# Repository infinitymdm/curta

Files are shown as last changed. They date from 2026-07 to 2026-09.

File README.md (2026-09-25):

# 3D-Printable Curta Type II

This repository contains my work on 3D-printable parts for a working Curta Type
II at 3:1 scale.

The 3D-printed curta so far

This work would not be possible without
[Marcus Wu's Curta Type I at 3x scale](https://www.thingiverse.com/thing:1943171),
[Mads Eskildsen's detailed Curta Type II model](https://www.thingiverse.com/thing:4146906),
and the treasure trove of engineering drawings on
[VCALC.net](https://www.vcalc.net/cu.htm). Marcus Wu's work informs many of the
manufacturing and assembly techniques used here for Mads Eskildsen's models. The
engineering drawings inform a few corrections to components from Eskildsen's
work.

# Components

Each subsection below contains a list of the component part numbers for the
relevant subsystem. I've tried to put these in roughly the same order that I
printed them in. Subsystem groupings are based on my own intuition about the way
the Curta Type II works.

Each subsection may also refer to a 3mf file containing the parts for that
subsystem. Not all parts match the original design. I've combined quite a few
into "composite" parts for convenience. Where this has been done, I've noted
where you can find my modified STL.

## Inner Frame

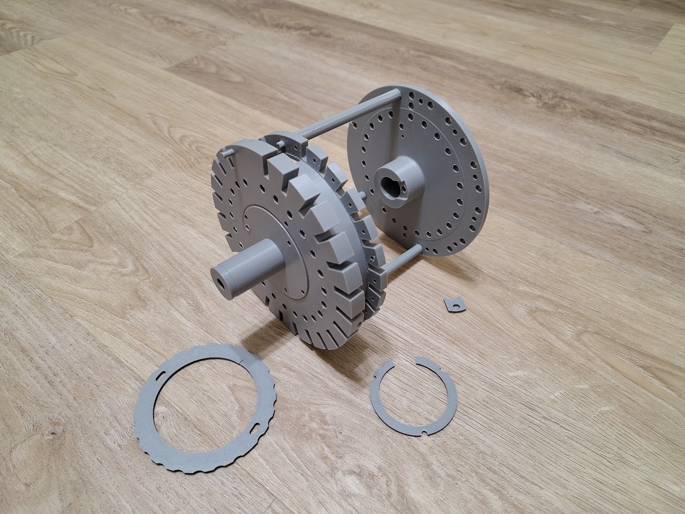
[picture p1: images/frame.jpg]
3D-printed Curta Type 2 frame components


See frame.3mf.

| Part Number | Quantity | Description |
| --- | --- | --- |
| 10154 | 1 | Name plate? |
| 2060 | 1 | Carriage body |
| 2030 | 1 | Bearing plate |
| 2062 | 3 | Frame columns |
| 2061 | 1 | Carriage stop pin |
| 2052 | 1 | Tens bell bearing plate |
| 2065 | 1 | Transmission crown hold-down plate |
| 10010 | 1 | Reversing ring guide |
| 10015 | 1 | Screw securing reversing ring guide to bearing plate |
| 10152 | 1 | Washer for 10015 (Not needed) |
| VSM 12124 3 | 7 | Tens bell bearing plate & transmission guide screws  |
| 2074 | 6 | Nut for frame columns |

## Step Drum

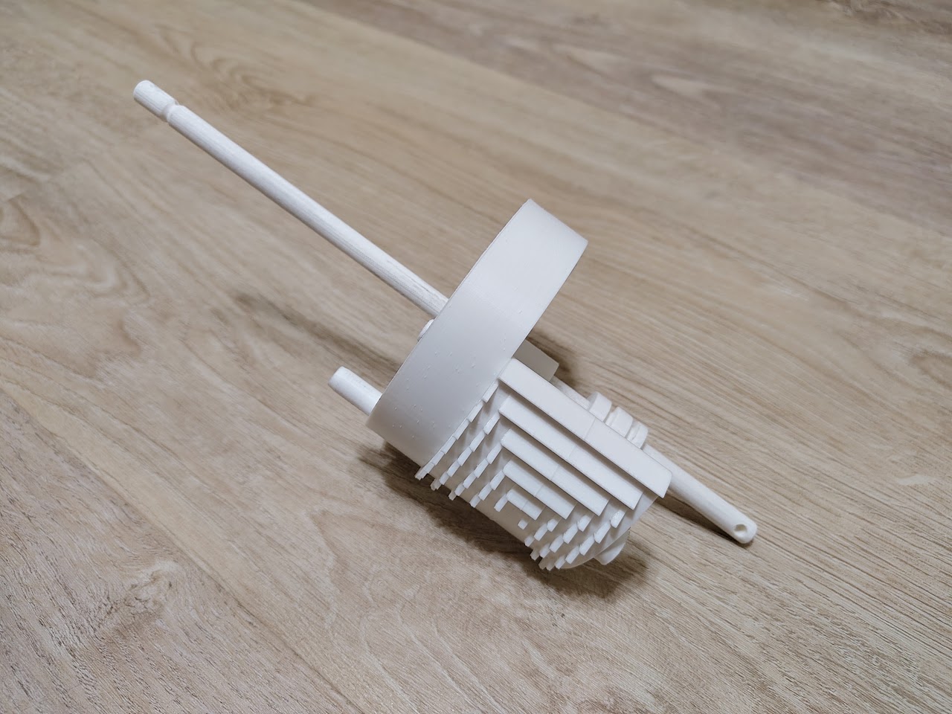
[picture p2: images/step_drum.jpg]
3D-printed Curta Type 2 step drum


See step_drum.3mf.

> [!NOTE]
> There is quite a bit more optimization to be done here. For now I'm printing
> the step drum in several parts, then assembling in a similar manner to the
> original design. A more optimal approach would be to design a single part
> combining all components except 2018 into a single much larger step drum.
> Teeth could still potentially use the composite parts here.
>
> Marcus Wu's design split the drum into two halves, but this also made the main
> axle (2018) a primary failure point. I'd like to keep 2018 a replaceable
> component so that it can be machined from tougher materials if need be.

> [!NOTE]
> Eskildsen's model has an error in part 10068 (main axle reversing ring) where
> the pin hole is offset 90 degrees from where it should be. I've replaced this
> with a custom model.

### Main axle and base

| Part Number | Quantity | Description |
| --- | --- | --- |
| 10068 | 1 | Reversing ring |
| 2018 | 1 | Main axle |
| 10069 | 1 | Pin for vertical stop |
| 2001 | 1 | Step drum base |
| 2002 | 2 | Dowels for subtract-only teeth |
| 2004 | 1 | Long dowel for step drum teeth (goes closer to slot) |
| 2003 | 1 | Short dowel for step drum teeth (goes further from slot) |
| 2016 | 1 | Screw for subtract-only teeth |
| 2017 | 1 | Screw for main step drum teeth |
| 12770 6 | 1 | Pin for step drum |

### Stepper teeth

> [!NOTE]
> Printed as 3 parts. See composites/*_steppers.stl

| Part Number | Quantity | Description |
| --- | --- | --- |
| 2005 | 1 | 10-tooth stepper |
| 2014 | 4 | 1-tooth stepper (double thickness) |
| 2006 | 3 | 9-tooth stepper |
| 2013 | 4 | 2-tooth stepper |
| 2007 | 2 | 8-tooth stepper |
| 2012 | 4 | 3-tooth stepper |
| 2008 | 2 | 7-tooth stepper |
| 2011 | 4 | 4-tooth stepper |
| 2009 | 2 | 6-tooth stepper |
| 2010 | 4 | 5-tooth stepper |

## Tens Bell

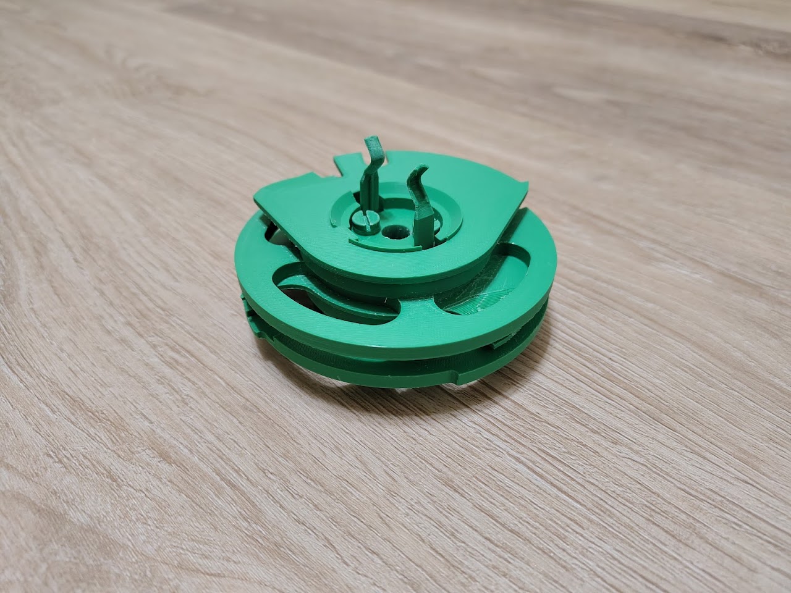
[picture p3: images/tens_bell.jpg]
3D-printed Curta Type II tens bell


See tens_bell.3mf.

### Tens Bell Body

> [!NOTE]
> Printed as 1 part. See composites/carry_resets.stl

| Part Number | Quantity | Description |
| --- | --- | --- |
| 2045 | 1 | Tens bell body |
| 2046 | 1 | Upper locking ring |
| 2048 | 1 | Upper carry reset  |
| 2049 | 1 | Lower locking ring |
| 2050 | 1 | Lower carry reset  |
| 2047 | 2 | Spacer |

### Spring & Mounting

| Part Number | Quantity | Description |
| --- | --- | --- |
| 10070 | 1 | Tens bell spring (Replace with [mwu's tens_bell_spring.stl](https://www.thingiverse.com/thing:1943171)) |
| VSM 12124 | 2 | Tens bell spring screws |
| 2051 | 1 | Tens bell spring mounting plate |
| 2053 | 2 | Tens bell screws |

## Zeroing & Anti-reversal

See zeroing_disc.3mf.

### Zeroing Disc

> [!WARNING]
> The anti-reversal teeth on the zeroing disc (2031) are very small. This might
> need to be modified so the anti-reversal pawl has a little more space between
> teeth to catch onto.

| Part Number | Quantity | Description |
| --- | --- | --- |
| 2031 | 1 | Zeroing disc |
| 2023 | 1 | Zeroing disc pin |
| 10114 | 1 | Zeroing arm |
| 10112 | 1 | Zeroing bearing |
| 10118 | 1 | Zeroing disc clip |
| 2037 | 1 | Zeroing bearing screw |
| 2035 | 1 | Zeroing arm screw |
| 2034 | 1 | Zeroing arm screw sleeve |
| 2038 | 1 | Zeroing arm spring (Make from 1.1mm spring wire) |
| 2074 | 1 | Nut for zeroing arm screw |

### Anti-reversal Pawl

| Part Number | Quantity | Description |
| --- | --- | --- |
| 10113 | 1 | Anti-reversal pawl |
| 2042 | 1 | Anti-reversal pawl screw |
| 2041 | 1 | Anti-reversal pawl screw sleeve |
| 10058 | 1 | Anti-reversal pawl spring (Make from 0.6mm spring wire) |
| 2074 | 1 | Nut for anti-reversal pawl screw |

### Carriage Lock

| Part Number | Quantity | Description |
| --- | --- | --- |
| 2163 | 1 | Carriage lock ring |
| 2122 | 1 | Carriage lock pin  |

## Transmission Axles

See trans_axles.3mf.

> [!NOTE]
> These are printed 1 at a time. Each plate's name indicates how many times it
> should be printed.

> [!NOTE]
> I've made a few modifications to these models:
>
> 1. Axles are printed with a 4% reduction in diameter. This saves a bit of
>    post-processing.
> 2. I've replaced the crown gears (2063) with a custom model which is keyed for
>    the axles.

> [!WARNING]
> 10097 is probably too thin to be useful once printed. May need to find or
> design an easily-printable replacement.

| Part Number | Quantity | Description |
| --- | --- | --- |
| 2064 | 17 | Transmission axle |
| 2064-2 | 1 | Transmission axle with clip slots for lowest input slider digit |
| 2064-3 | 4 | Transmission axle with clip slots for upper result carry outputs |
| 2064-4 | 1 | Transmission axle with clip slots for lowest reversal slider digit |
| 2063 | 23 | Crown gear for transmission axles |
| 10097 | 12 | Transmission gear locating clip |

## Transmission gears

See trans_gears.3mf

### Step gear

> [!NOTE]
> Printed as 1 part. See composites/gear_step.stl

| Part Number | Quantity | Description |
| --- | --- | --- |
| 10038 | 21 | Transmission step gear |
| 10140 | 21 | Transmission gear short sleeve |
| 10141 | 21 | Transmission gear 4.8mm spacer |

### Lock gear

> [!NOTE]
> Printed as 1 part. See composites/gear_lock.stl

| Part Number | Quantity | Description |
| --- | --- | --- |
| 2066 | 2 | Transmission gear medium sleeve for carry inputs |
| 10141 | 2 | Transmission gear 4.8mm spacer |
| 2073 | 2 | Transmission hold gear |

### Step-lock gear

> [!NOTE]
> Printed as 1 part. See composites/gear_step_lock.stl

| Part Number | Quantity | Description |
| --- | --- | --- |
| 10055 | 21 | Transmission gear medium sleeve |
| 10038 | 21 | Transmission step gear |
| 2073 | 21 | Transmission hold gear |
| 10051 | 21 | Transmission gear 5.7mm spacer  |
| 10054 | 21 | Transmission gear 3.9mm spacer  |

### Double step gear

> [!NOTE]
> Printed as 1 part. See composites/gear_step2.stl

| Part Number | Quantity | Description |
| --- | --- | --- |
| 10038 | 2 | Transmission step gear |
| 10041 | 1 | Transmission gear 5.4mm spacer |
| 10110 | 1 | Transmission gear 4.5mm spacer |
| 10032 | 1 | Transmission gear long sleeve for result carry input |

### Triple step gear

> [!NOTE]
> Printed as 1 part. See composites/gear_step3.stl

| Part Number | Quantity | Description |
| --- | --- | --- |
| 10038 | 3 | Transmission step gear |
| 10042 | 2 | Transmission gear 3mm spacer |
| 10020 | 1 | Transmission gear long sleeve for turn count carry input |
| 10041 | 1 | Transmission gear 5.4mm spacer |

## Input Assemblies

See input_assemblies.3mf.

### Input Sliders

> [!NOTE]
> Printed as 1 part. See composites/input_slider.stl

| Part Number | Quantity | Description |
| --- | --- | --- |
| 10075 | 11 | Input slider alignment screw |
| 10057 | 11 | Input slider |
| kugel 1.8 | 11 | Input slider detent ball bearing (5.4mm) |
| 10073 | 11 | Input slider detent spring (Make from clipped pen springs) |
| 10146 | 11 | Input slider spring backing (not used) |

### Input Shafts

| Part Number | Quantity | Description |
| --- | --- | --- |
| 10061 | 11 | Input shaft (Replace with [mwu's selector_shaft_bootom_x8.stl](https://www.thingiverse.com/thing:1943171)) |
| 10029 | 11 | Input dial (Replace with [mwu's selector_shaft_top.stl](https://www.thingiverse.com/thing:1943171)) |
| 2102 | 1 | Input shaft upper digit bearing cover |
| 2101 | 2 | Input shaft lower digit bearing cover |
| 2100 | 11 | Input shaft bearing |
| VSM 12124 3 | 6 | Input shaft bearing cover screw (Replace with M4x10 pan head) |

## Reversal Switch

See reversal_switch.3mf

### Shaft and spacers

| Part Number | Quantity | Description |
| --- | --- | --- |
| 2086 | 1 | Reversal slider shaft |
| 2091 | 1 | Reversal slider lower shaft spacer |
| 2092 | 1 | Reversal slider upper shaft spacer |

### Reversal Slider

> [!NOTE]
> To save a bit of sanding, I increased the height of 2090 by a few layers. This
> might come back to bite me, but I think it's probably fine.

| Part Number | Quantity | Description |
| --- | --- | --- |
| 2155 | 2 | Reversal slider assembly screws |
| Halbrundneite 1,5 x 3 | 2 | Reversal slider rivets |
| 2088 | 1 | Reversal slider |
| 2089 | 2 | Reversal slider layer |
| 2090 | 1 | Reversal slider layer spacer |
| kugel 1.8 | 1 | Input slider detent ball bearing (5.4mm) |
| 100023 | 1 | Reversal slider detent spring (Make from clipped pen springs) |

## Carry Levers

See carry_levers.3mf.

> [!WARNING]
> It's very clear that the original carry levers are designed for sheet metal
> manufacturing. I've replaced these with custom models which have reinforced
> arms to help the tens bell push the levers up and down. I'm still testing my
> custom models for these for fit and durability.

| Part Number | Quantity | Description |
| --- | --- | --- |
| 2106 | 21 | Carry slider |
| 2105 | 21 | Carry spring cover |
| 2108 | 7 | Carry lever for turn count |
| 2109 | 14 | Carry lever for results |
| 2107 | 21 | Carry spring (Make from 0.6mm spring wire) |

## Upper Carriage

See upper_carriage.3mf.

> [!NOTE]
> Mads Eskildsen's model for 2130 has a slightly too large outer diameter which
> doesn't leave enough space for the teeth on the bottom of the clearing cap.
> I've replaced this with a corrected custom model.
>
> I also combined 2146 and 2162 into a single part for ease of printing, and
> strengthened 2162 by increasing the thickness of each arm to compensate for
> the weak plastic and larger size.

| Part Number | Quantity | Description |
| --- | --- | --- |
| 2130 | 1 | Carriage body |
| 2131 | 1 | Carriage detent slider |
| 2133 | 1 | Carriage detent pin |
| 2135 | 23 | Output dial pin |
| 2146 | 1 | Carriage detent plate |
| 2162 | 1 | Spider spring |
| kugel 2 | 25 | Carriage ball bearing (6mm) |
| 2132 | 1 | Carriage detent pin spring (Make from pen spring) |

## Output Dials

> [!NOTE]
> I modeled custom dials with embossed numbers, like the dials
> [dwildstar did on Thingiverse](https://www.thingiverse.com/thing:3178684) The
> half-pins still have to be printed separately and assembled though.

| Part Number | Quantity | Description |
| --- | --- | --- |
| 2136 | 4 | Lower digit ouptut dial |
| 2137 | 19 | Upper digit output dial |
| 2138 | 21 | Output dial carry half-pin |

## Upper Shell

| Part Number | Quantity | Description |
| --- | --- | --- |
| 2141 | 1 | Upper knurling |
| 2140 | 1 | Upper faceplate |
| 2147 | 2 | Pin for upper knurling |
| 2111 | 1 | Upper shell |
| 2110 | 3 | Upper shell screw (Replace with M3x10) |

### Carriage Exterior Support

> [!NOTE]
> Printed as 1 part. See composites/carriage_exterior_support.stl

| Part Number | Quantity | Description |
| --- | --- | --- |
| 2143 | 1 | Carriage support castellation |
| 2144 | 1 | Carriage stop |
| 2145 | 1 | Upper exterior bevel |

## Main Crank & Clearing cap

See main_crank.3mf

### Clearing Cap

| Part Number | Quantity | Description |
| --- | --- | --- |
| 2154 | 1 | Clearing ring |
| 2153 | 1 | Clearing ring main post |
| 2158 | 1 | Clearing ring secondary post |
| 2150 | 1 | Clearing cap |
| 10142-1 | 1 | Inner clearing teeth (Replace with [mwu's clearing_cap_teeth_x2.stl](https://www.thingiverse.com/thing:1943171)) |
| 2152 | 1 | Clearing teeth spacer (Replace with [mwu's clearing_cap_tooth_segment_spacer.stl](https://www.thingiverse.com/thing:1943171)) |
| 10142-2 | 1 | Outer clearing teeth (Replace with [mwu's clearing_cap_teeth_x2.stl](https://www.thingiverse.com/thing:1943171)) |
| 10033 | 1 | Funny anti-reversal doodad? (May not be needed) |

### Crank

| Part Number | Quantity | Description |
| --- | --- | --- |
| 10242 | 1 | Main crank |
| 10012 | 1 | Main crank handle |
| 10109 | 1 | Main crank handle screw |
| 12770 12 | 1 | Main crank pin |

### Crank collar

> [!NOTE]
> I've replaced the crank collar (2160) and nut (2164) with a custom version
> with printable threads. You'll want to print these with a pretty fine layer
> height (0.2mm or less) to make sure they work well.

| Part Number | Quantity | Description |
| --- | --- | --- |
| 2168 | 1 | Carriage c-clip |
| 2166 | 1 | Carriage upper spring spacer |
| 2165 | 1 | Carriage spring |
| 2160 | 1 | Crank collar |
| 2161 | 1 | Carriage lower spring spacer |
| 2167 | 1 | Crank collar washer (May not be needed?) |
| 2164 | 1 | Cranc collar nut |

## Lower Housing

See lower_housing.3mf

> [!NOTE]
> Optionally printed as 1 part. See lower_shell.stl.
>
> For some reason Mads Eskildsen's models don't include a bottom cover (2120). I
> modeled this based on the engineering drawings.

| Part Number | Quantity | Description |
| --- | --- | --- |
| 2119 | 1 | Main body shell |
| 2115 | 1 | Lower knurling |
| 2120 | 1 | Bottom cover |
| 12142 | 2 | Bottom cover screw |

## Decimal Markers

| Part Number | Quantity | Description |
| --- | --- | --- |
| 10046 | 9 | Point marker |
| 10047 | 9 | Point marker spring |
| kugel 1 | 9 | Point marker ball bearing (3mm) |
| 2118 | 2 | Decimal marker lock screw |

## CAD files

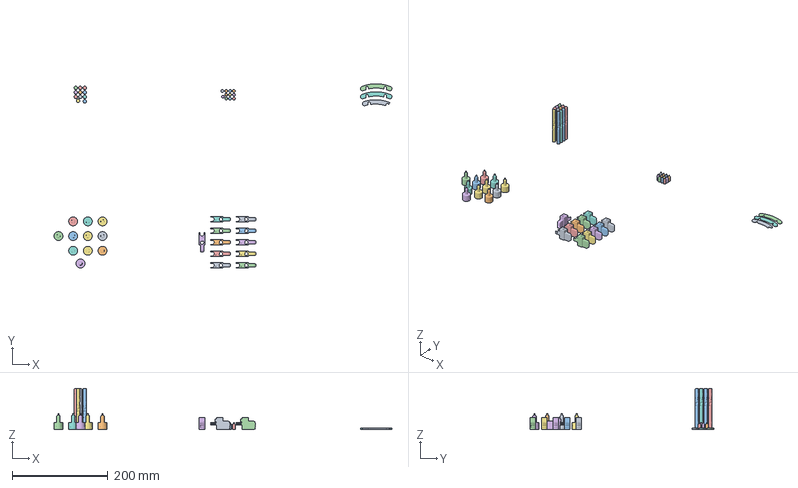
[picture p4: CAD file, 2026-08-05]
3mf/input_assemblies.3mf
704.2 x 384.2 x 86.1 mm
input_slider.stl x 11
selector_shaft_bottom_x8.stl x 11
selector_shaft_top.stl x 11

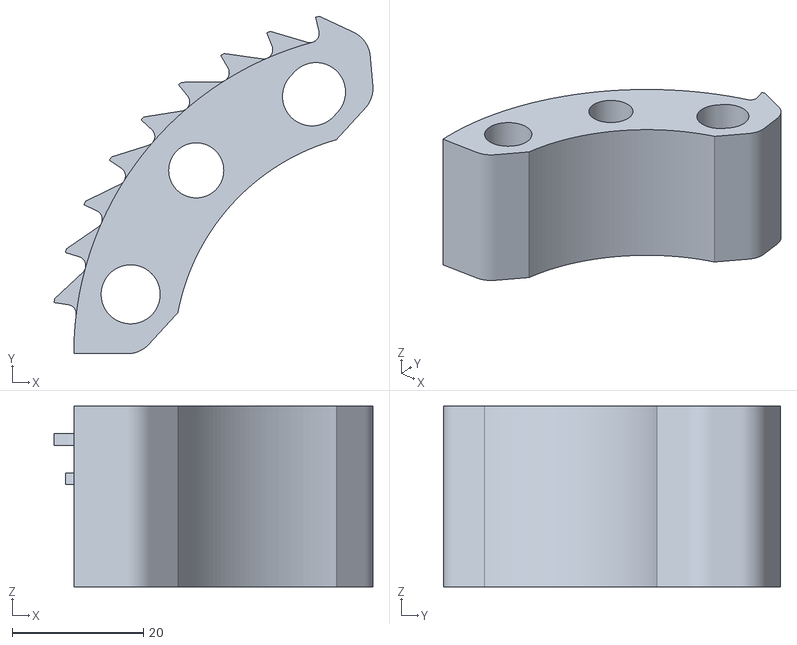
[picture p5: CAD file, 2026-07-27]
composites/main_upper_steppers.stl
48.7 x 51.5 x 27.6

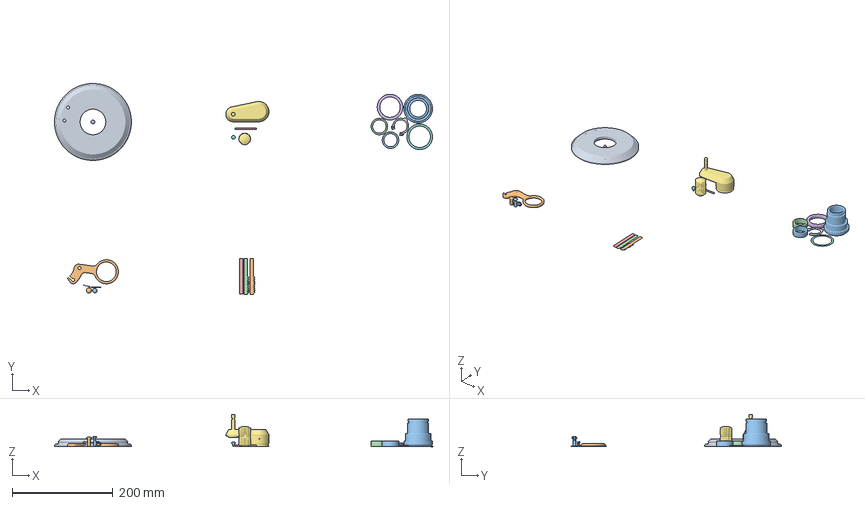
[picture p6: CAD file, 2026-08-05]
3mf/main_crank.3mf
752.0 x 419.7 x 64.5 mm
clearing_cap_teeth_x2.stl x 2
clearing_cap_tooth_segment_spacer.stl

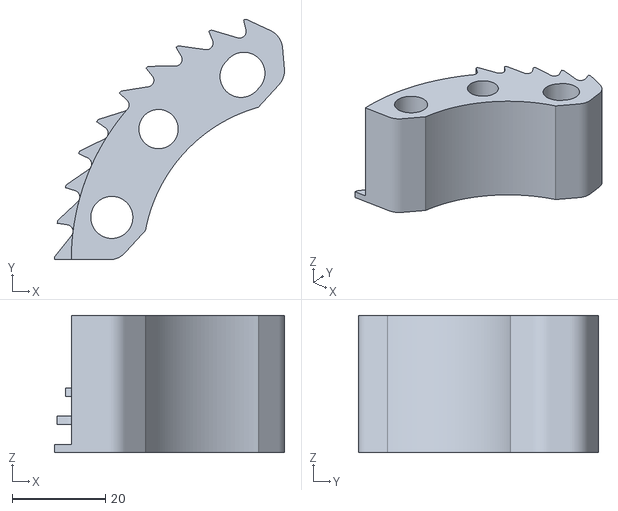
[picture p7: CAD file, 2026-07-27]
composites/main_lower_steppers.stl
49.2 x 51.5 x 29.4

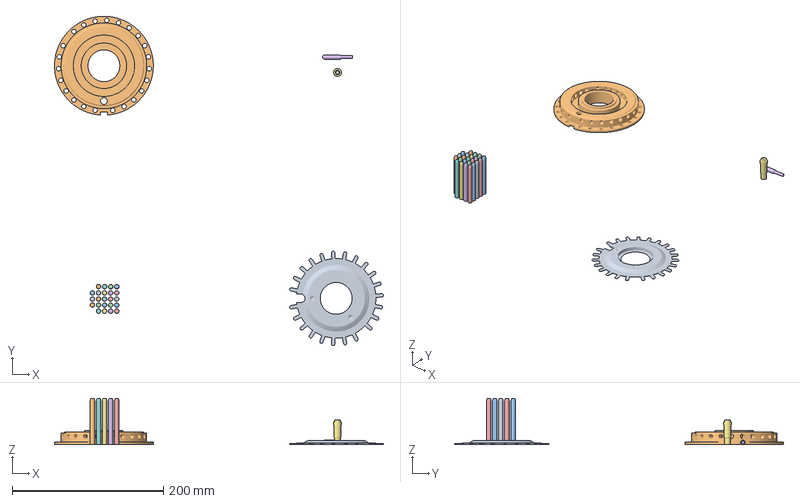
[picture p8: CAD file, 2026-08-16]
3mf/upper_carriage.3mf
434.4 x 434.9 x 61.2 mm
2146_2162_spider_spring_and_detent_plate.stl
2130_upper_carriage_body.stl

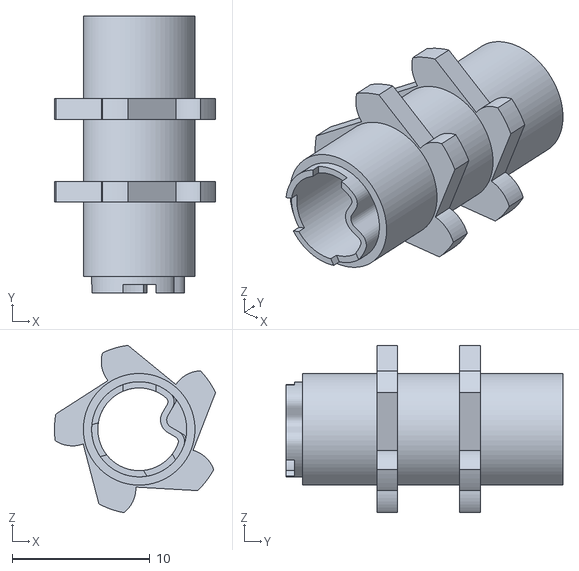
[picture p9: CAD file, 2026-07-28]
composites/gear_step2.stl
11.7 x 20.1 x 12.1

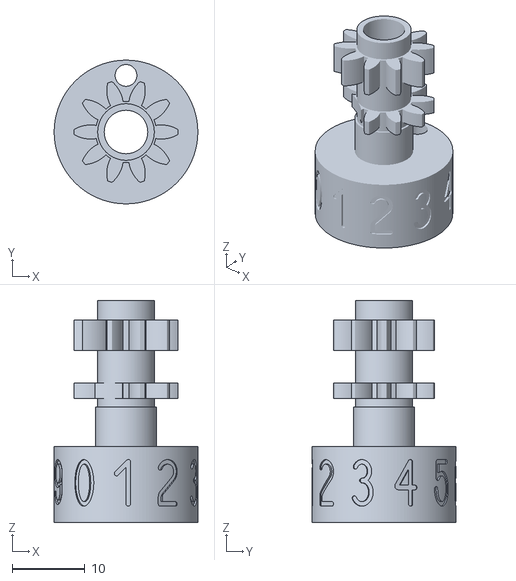
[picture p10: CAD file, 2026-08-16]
custom/2136_results_dial_type_I_with_digits.stl
19.8 x 19.8 x 30.6

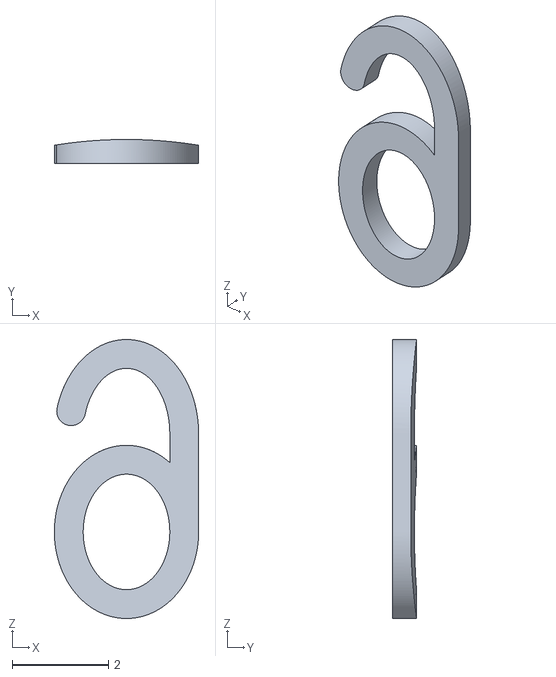
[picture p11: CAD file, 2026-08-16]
custom/source/results_dial_-_digit_6.stl
3.00 x 0.5 x 5.80

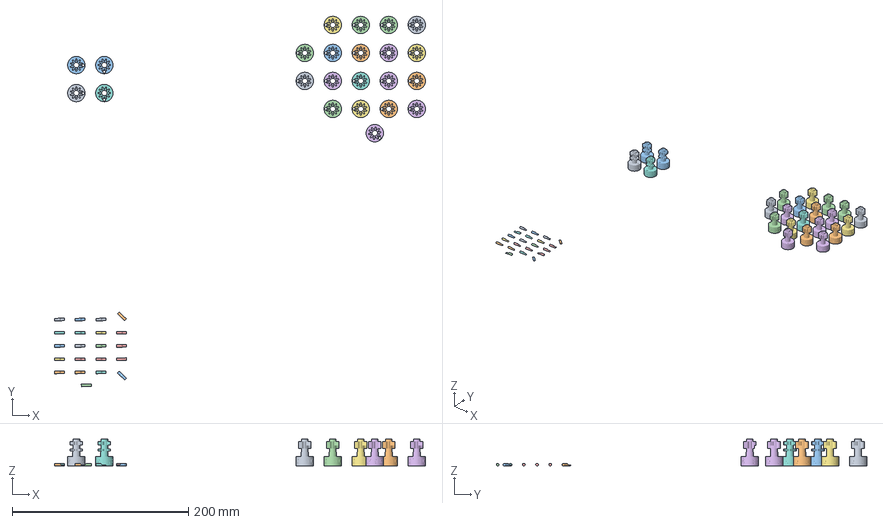
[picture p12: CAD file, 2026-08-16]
3mf/dials.3mf
421.4 x 420.9 x 30.6 mm
2137_results_dial_type_II_with_digits.stl x 19
2136_results_dial_type_I_with_digits.stl x 4

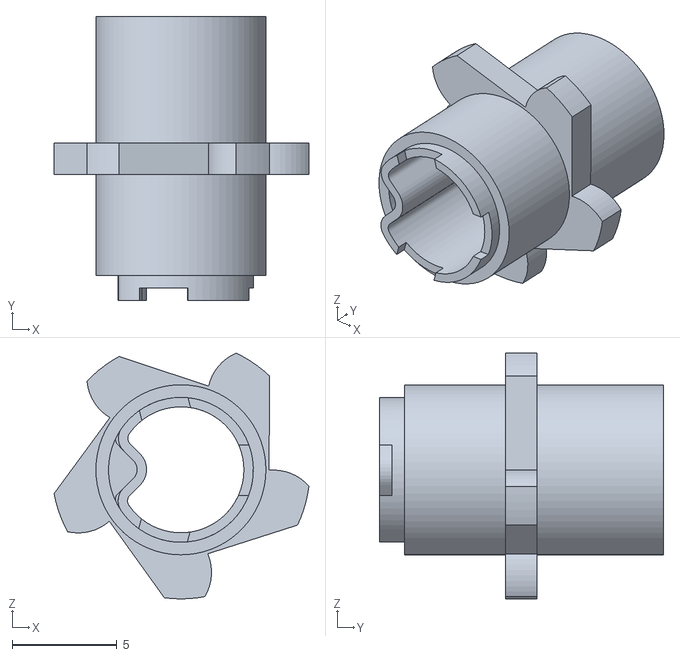
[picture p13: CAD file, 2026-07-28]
composites/gear_step.stl
12.1 x 13.5 x 11.7

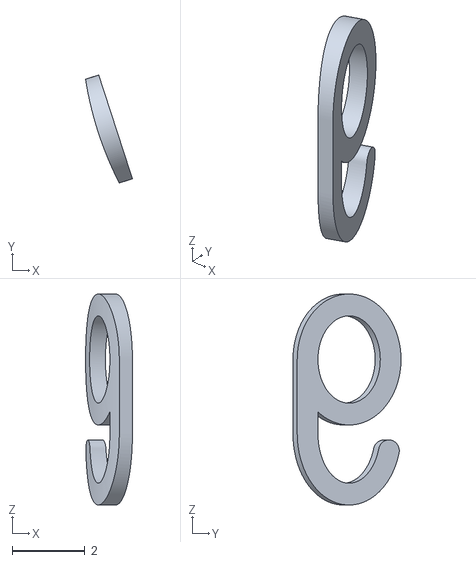
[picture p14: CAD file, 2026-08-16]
custom/source/results_dial_-_digit_9.stl
1.29 x 2.97 x 5.80

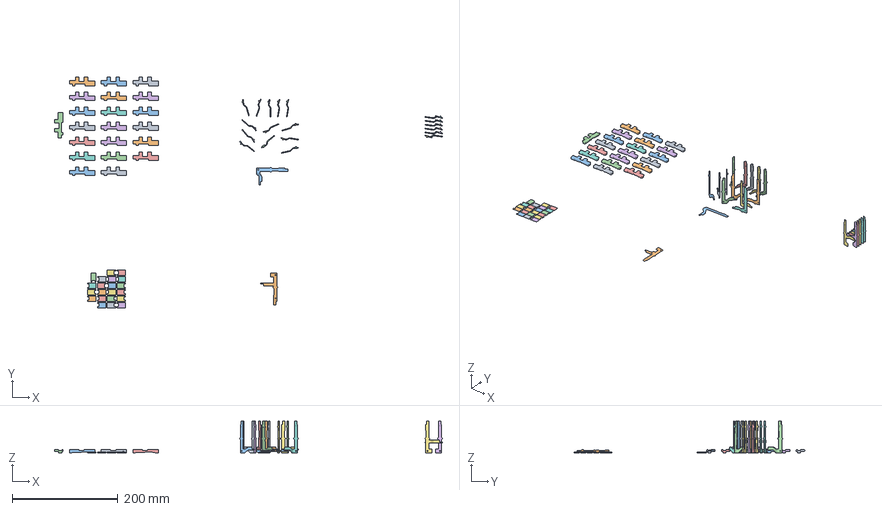
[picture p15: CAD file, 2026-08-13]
3mf/carry_levers.3mf
733.0 x 435.5 x 60.0 mm

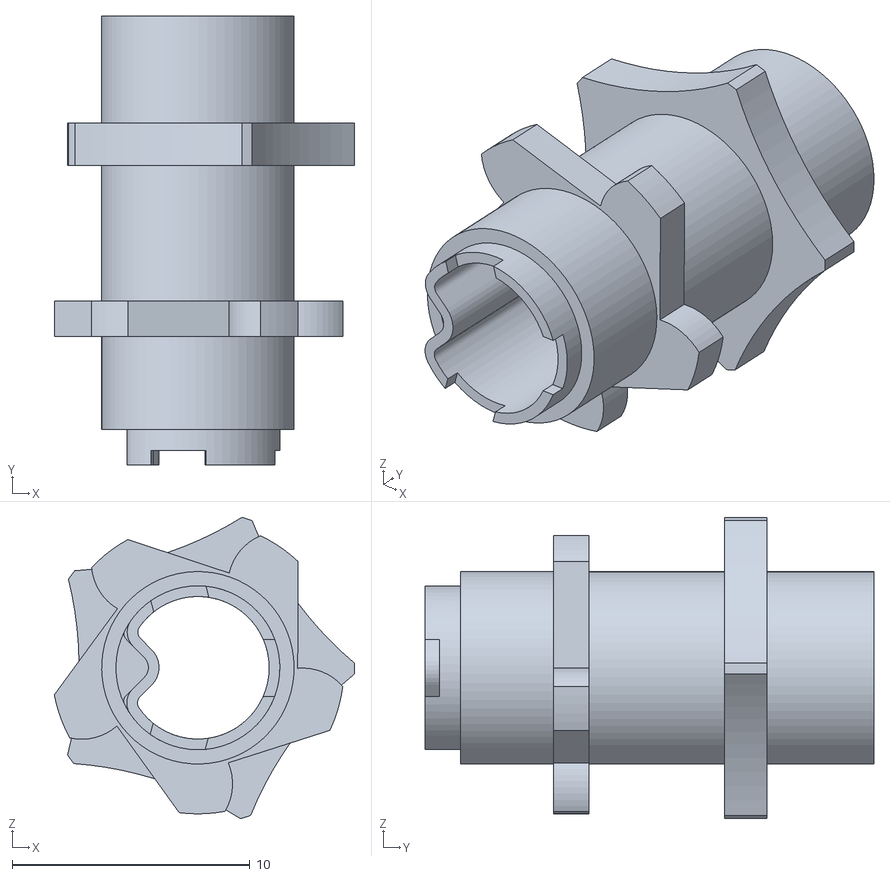
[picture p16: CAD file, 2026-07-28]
composites/gear_step_lock.stl
12.6 x 18.9 x 12.7

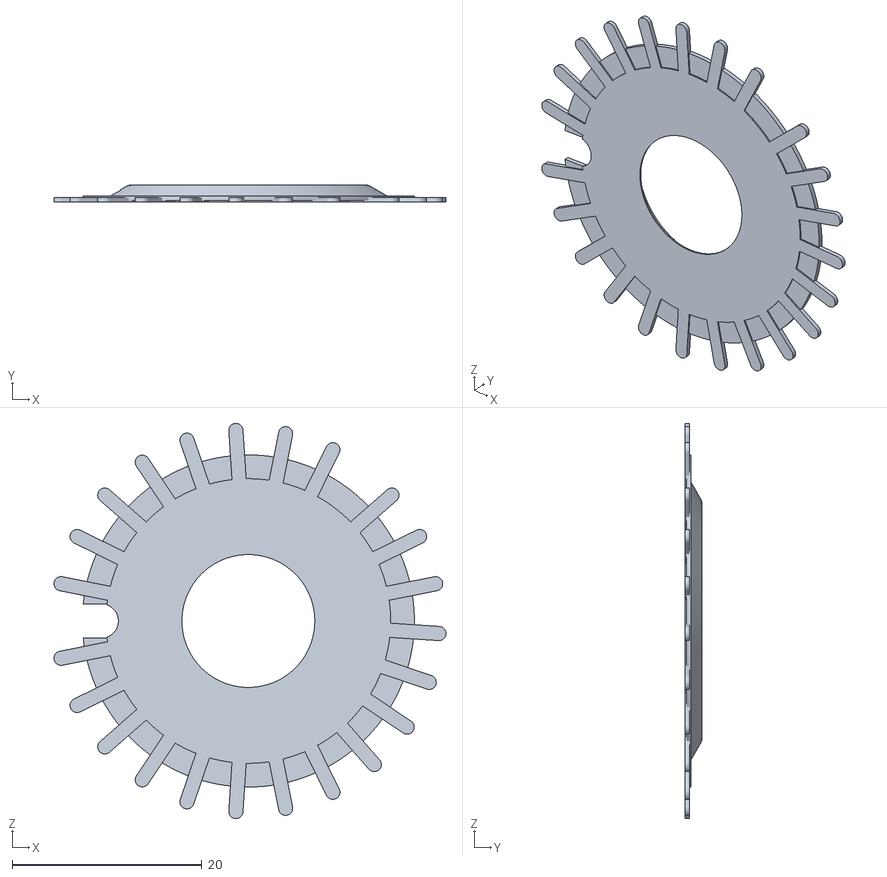
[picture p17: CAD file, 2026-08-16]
custom/2146_2162_spider_spring_and_detent_plate.stl
41.3 x 1.79 x 41.7

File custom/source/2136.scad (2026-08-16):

digit_scale = 3/2.8;

difference() {
    scale(3) rotate([0, 90, 180]) import("2136.stl"); 
    scale(digit_scale) {
        import("results_dial_-_digit_0.stl");
        import("results_dial_-_digit_1.stl");
        import("results_dial_-_digit_2.stl");
        import("results_dial_-_digit_3.stl");
        import("results_dial_-_digit_4.stl");
        import("results_dial_-_digit_5.stl");
        import("results_dial_-_digit_6.stl");
        import("results_dial_-_digit_7.stl");
        import("results_dial_-_digit_8.stl");
        import("results_dial_-_digit_9.stl");
    }
}

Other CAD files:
custom/2137_results_dial_type_II_with_digits.stl
custom/source/results_dial_-_digit_8.stl
3mf/lower_housing.3mf
composites/gear_lock.stl
custom/source/2137.scad
3mf/frame.3mf
3mf/reversal_switch.3mf
3mf/step_drum.3mf
3mf/tens_bell.3mf
3mf/trans_axles.3mf
3mf/trans_gears.3mf
3mf/upper_housing.3mf
3mf/zeroing_disc.3mf
composites/carriage_exterior_support.stl
composites/carry_resets.stl
composites/gear_step3.stl
composites/input_slider.stl
composites/lower_shell.stl
composites/secondary_steppers.stl
custom/10068_reversing_ring.stl
custom/2063_crown_gear.stl
custom/2120_bottom_cover.stp
custom/2130_upper_carriage_body.stl
custom/source/2136.stl
custom/source/2137.stl
custom/source/results_dial_-_digit_0.stl
custom/source/results_dial_-_digit_1.stl
custom/source/results_dial_-_digit_2.stl
custom/source/results_dial_-_digit_3.stl
custom/source/results_dial_-_digit_4.stl
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

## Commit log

2026-07-27 Initial README & 3mf files
    [carriage_exterior_support.stl, carry_levers.3mf, carry_resets.stl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]
2026-07-28 Add composite transmission gears
    [carry_levers.3mf, frame.3mf, gear_lock.stl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]
2026-07-29 Use mwu's tens bell spring, update stepper gears
    [step_drum.3mf, tens_bell.3mf]
2026-07-30 Add custom reversing ring
    [10068_reversing_ring.stl]
2026-07-30 Update print files
    [step_drum.3mf, trans_gears.3mf, zeroing_disc.3mf]
2026-07-30 Add images of printed assemblies
    [step_drum.3mf, tens_bell.3mf, trans_axles.3mf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]
2026-07-31 Add custom crown gears
    [crown_gear.stl, trans_axles.3mf]
2026-07-31 Update crown gear and move carriage lock
    [crown_gear.stl, lower_housing.3mf, tens_bell.3mf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]
2026-08-05 Add custom bottom cover and carriage body
    [2120_bottom_cover.stp, 2130_upper_carriage_body.stp, dials.3mf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]
2026-08-05 Fix carriage body, add spider spring custom composite part
    [2130_upper_carriage_body.stp, 2146_2162_spider_spring_and_detent_plate.stl, lower_housing.3mf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]
2026-08-12 Add results dials with digits
    [2136_with_digits.stl, 2137_with_digits.stl]
2026-08-13 Fix carriage body and spider spring
    [2130_upper_carriage_body.stl, 2130_upper_carriage_body.stp, 2146_2162_spider_spring_and_detent_plate.stl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]
2026-08-13 Add custom dials
    [dials.3mf]
2026-08-16 Fix custom dials and add sources
    [2063_crown_gear.stl, 2136.scad, 2136.stl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]
